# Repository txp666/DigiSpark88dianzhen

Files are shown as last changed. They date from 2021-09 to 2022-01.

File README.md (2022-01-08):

# 88dianzhen
点阵-小玩具

1 在vscode中安装插件PlatformIO  
2 在PlatformIO中新建一个项目用来安装板子，选择board————digisparkTiny  
3 在vscode中打开文件夹《platform》  
4 安装digispark驱动 《digispark Driver》  
5 上传程序  
电池型号：6020303.7v聚合物锂电池：https://item.taobao.com/item.htm?spm=a1z09.2.0.0.2a602e8dpFP4lD&id=623801880958&_u=t20q7cgb668e  
注意：点阵为共阴极  
按键可搜索小乌龟按键  
拨动开关 贴片 7脚两档/8脚三档 MSK-12C02/MSK-02（优信电子）  

更多采购信息请看AD文件夹

视频：[【自制】直男礼物…最小8*8点阵_哔哩哔哩_bilibili](https://www.bilibili.com/video/BV1jR4y1n7xD?spm_id_from=333.999.0.0)

           [【自制】手机把手教你做一个可编程8*8点阵【教程】_哔哩哔哩_bilibili](https://www.bilibili.com/video/BV1hq4y1y7wD/)

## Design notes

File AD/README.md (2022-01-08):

采购：

[digispark：风枪拆芯片](https://item.taobao.com/item.htm?spm=a230r.1.14.89.3bde6dfdx7clx8&id=531487308323&ns=1&abbucket=19#detail)

[拨动开关 贴片 7脚两档/8脚三档 MSK-12C02/MSK-02](https://item.taobao.com/item.htm?spm=a1z09.2.0.0.27f82e8dUXrg1G&id=557092773462&_u=q20q7cgb67b0)

[日本ALPS 轻触 贴片侧按键开关 SKSCPCE010 3.5*3.55*1.25 小乌龟-淘宝网 (taobao.com)](https://item.taobao.com/item.htm?spm=a1z09.2.0.0.8ae02e8d8QCrer&id=624742635251&_u=820q7cgb1b66)

[贴片USB-3.1插座 Type-C母座 16P](https://item.taobao.com/item.htm?spm=a1z10.3-c-s.w4002-21223910208.13.7e0c6a4bq6PU4E&id=573090887123)

[TP4056 SOIC-8 1A 线性锂离子电池充电器芯片](https://item.taobao.com/item.htm?spm=a1z10.3-c-s.w4002-21223910208.18.77656a4bx6ipQr&id=522573697765)

[电池型号：6020303.7v聚合物锂电池](https://item.taobao.com/item.htm?spm=a1z09.2.0.0.2a602e8dpFP4lD&id=623801880958&_u=t20q7cgb668e)

[NCP1400ASN50T1G NCP1400A](https://item.taobao.com/item.htm?spm=a230r.1.14.1.48ac1ed7YLhlan&id=654362918143&ns=1&abbucket=19#detail) 

[SS310](https://item.taobao.com/item.htm?spm=a1z10.3-c-s.w4002-21223910208.9.1e566a4bXljj1N&id=589984076142)

[CD43 22UH(220) 绕线片式功率电感](https://item.taobao.com/item.htm?spm=a1z09.2.0.0.3ee12e8d0cIyYd&id=522576032553&_u=q20q7cgb161f)

[贴片钽电容 3528B 68uF](https://item.taobao.com/item.htm?spm=a1z09.2.0.0.3ee12e8d0cIyYd&id=616132727671&_u=q20q7cgb9b24)

[贴片钽电容 3216A 10V 10UF](https://item.taobao.com/item.htm?spm=a1z09.2.0.0.3ee12e8d0cIyYd&id=536882276924&_u=q20q7cgbe887)

[MAX7219点阵模块](https://item.taobao.com/item.htm?spm=a1z09.2.0.0.27f82e8duHfAoq&id=618274380277&_u=q20q7cgbf835)（风枪拆芯片）

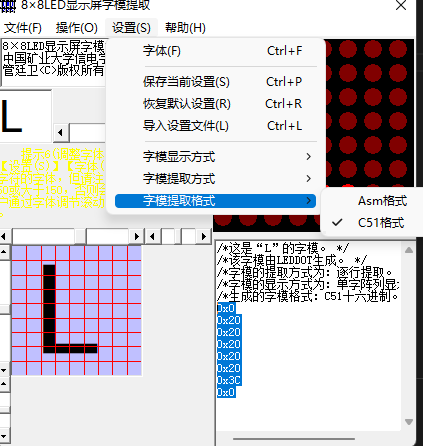
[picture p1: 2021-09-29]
点阵取模/设置.png

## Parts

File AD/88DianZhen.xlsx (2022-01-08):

Comment | Description | Designator | Quantity
10uF | Capacitor | C1, C6, C8, C10 | 4
0.1uF | Capacitor | C2, C3, C5, C7 | 4
4.7uF | Capacitor | C4 | 1
10uF |  | C9 | 1
68uF |  | C11 | 1
SS310 | 肖特基二极管 | D1, D2, D4 | 3
color? | LED | D3, D5 | 2
TP4056 | 锂电池充电管理 | IC1 | 1
HDR-1X2 | 2P接插件 | JP1 | 1
TACT 4P | Button | K1 | 1
22uH |  | L1 | 1
SLD1388DRA1GD |  | LED1 | 1
10K | Resistor | R1 | 1
12K | Resistor | R2, R3 | 2
66.5 | Resistor | R4, R5 | 2
0.4 | Resistor | R6 | 1
1K | Resistor | R7, R9, R11 | 3
2K | Resistor | R8 | 1
1.5k | Resistor | R10 | 1
MSK12C02 |  | SW1 | 1
MAX7219CWG |  | U1 | 1
ATTINY85-20SUR |  | U2 | 1
NCP1400ASN50T1G |  | U3 | 1
Type-C |  | USB1 | 1

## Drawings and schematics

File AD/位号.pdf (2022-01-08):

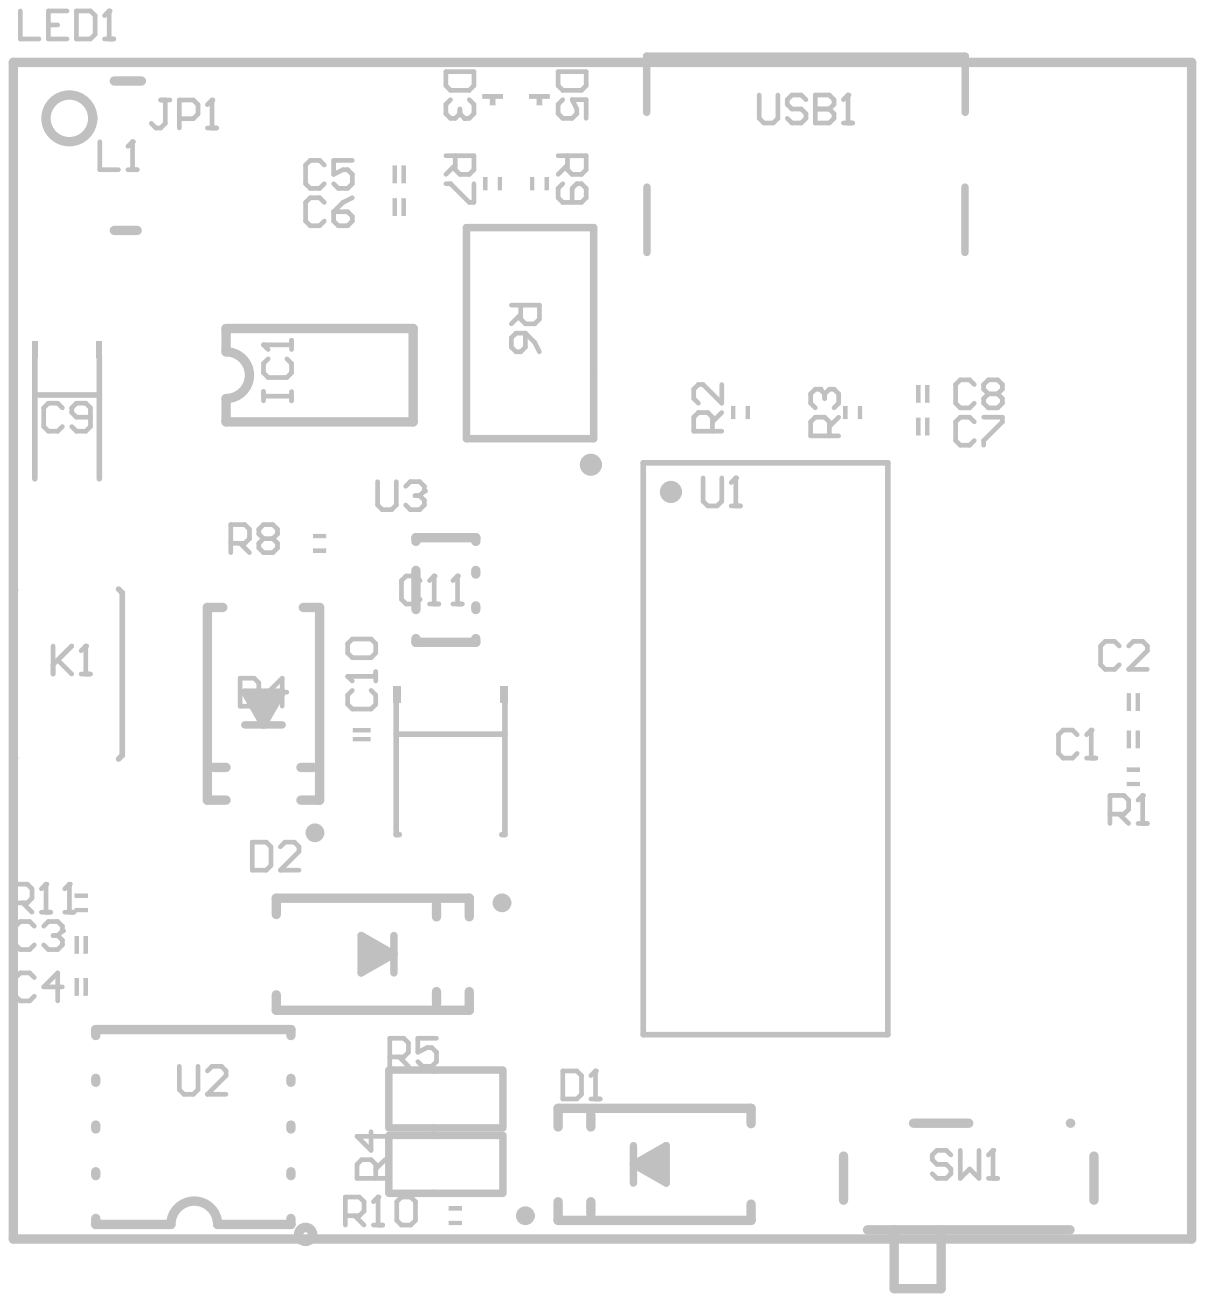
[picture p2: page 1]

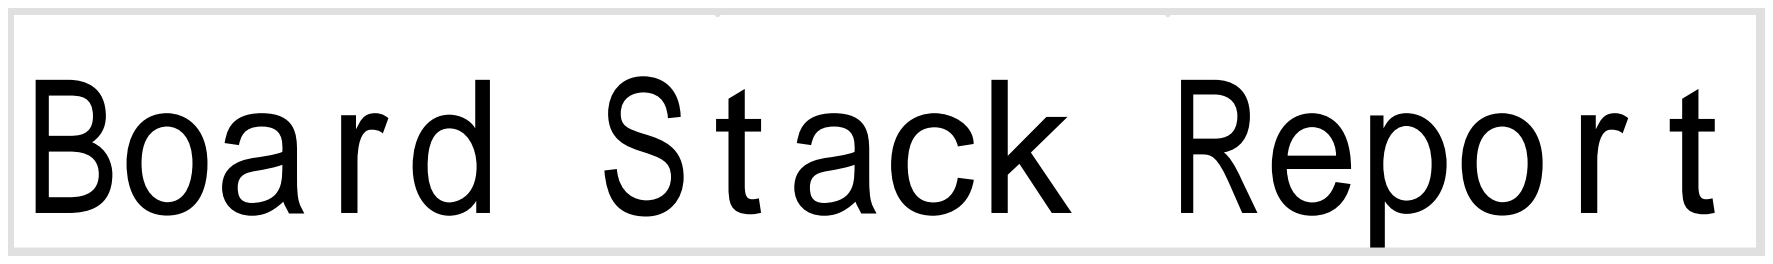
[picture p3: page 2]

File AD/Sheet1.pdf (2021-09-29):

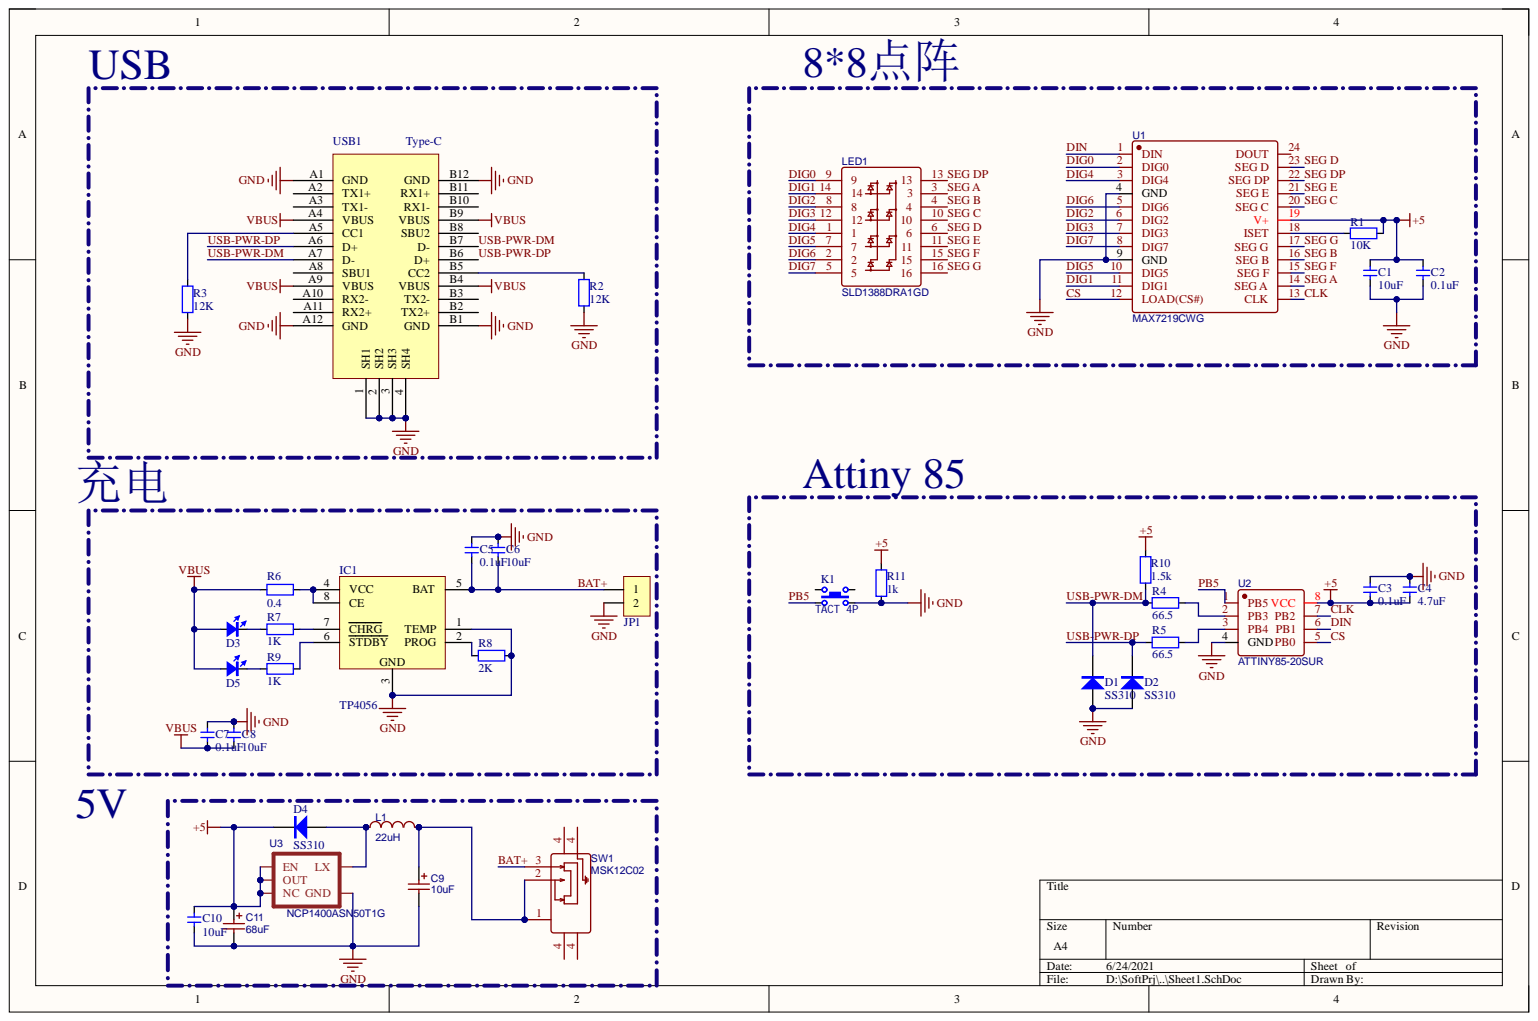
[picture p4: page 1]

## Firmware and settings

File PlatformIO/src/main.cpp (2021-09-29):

 

#include <LedControl.h>
 
int DIN = 1;
int CS =  0;
int CLK = 2;
int Button = 3;//按键
int Num = 0;
byte L[8]=     {0x20,0x20,0x20,0x20,0x20,0x20,0x20,0x3E};  //L
byte O[8]=     {0x18,0x24,0x42,0x42,0x42,0x42,0x24,0x18};  //O
byte V[8]=     {0x81,0x81,0x81,0x81,0x81,0x42,0x24,0x18};  //V
byte E[8]=     {0x7E,0x40,0x40,0x7E,0x40,0x40,0x40,0x7E};  //E
byte samllheart[8] = { 0x0,0x24,0x5A,0x42,0x24,0x18,0x0,0x0};  //小心心
byte bigheart[8] = { 0x66,0x99,0x81,0x81,0x81,0x42,0x24,0x18 };  //大心心
byte smile[8]=   {0x3C,0x42,0xA5,0x81,0xA5,0x99,0x42,0x3C};//笑脸
  
LedControl lc=LedControl(DIN,CLK,CS,4);
 //点阵显示函数
void key()
{
   
    if (digitalRead(Button) == LOW)
    {
        delay(30);
        if (digitalRead(Button) == LOW)
        {
            Num++;//按键按下后
            
            
            while (digitalRead(Button) == LOW);
        }
    }
}
void printByte(byte character [])
{
  int i = 0;
  for(i=0;i<8;i++)
  {
    lc.setRow(0,i,character[i]);
  }
}
void setup(){
 lc.shutdown(0,false);       //启动时，MAX72XX处于省电模式
 lc.setIntensity(0,8);       //将亮度设置为最大值
 lc.clearDisplay(0);         //清除显示
 pinMode(Button, INPUT);// 按键引脚设置上拉输入
}
 
void loop(){ 

    key();
    if (Num >1)
        Num=0;
    if (Num==0){
        printByte(samllheart);
        delay(500);
        printByte(bigheart);
        delay(500);
    }
   
     
    if (Num==1)
        printByte(smile);
        
    
   //printByte(smile);
}
 

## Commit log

2021-09-29 取模软件
2021-12-26 创建 README.md
2021-12-26 更新 README.md
2021-12-29 pcb更新
    [88DianZhen.PrjPcb]
2022-01-08 添加位号图、更新按键开关链接
    [88DianZhen.xlsx]
